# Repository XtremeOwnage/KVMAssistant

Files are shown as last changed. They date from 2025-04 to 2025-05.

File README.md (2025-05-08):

# KVMAssistant

Hardware based solution for home-assistant control over KVMs.

The initial goal of this project is to enable plug and play home assistant control over common off the shelf consumer KVM units.

I have multiple CKL-KVM units to test with, as well as no-name unit, and a TESSMart.

Depending, on how much interest this project gets, depends on how far it goes.

Board was originally built with KiCAD, but, moved to EasyEDA as getting the correct parts was quite a bit easier.

If you wanted to build one, every EXCEPT the ESP will cost.... under 3$.

## Coming soon

Initial schematic design completed. Not perfect, but, good enough to send in an order for PCBs and parts.

Parts were ordered a few weeks ago, pending arrival.

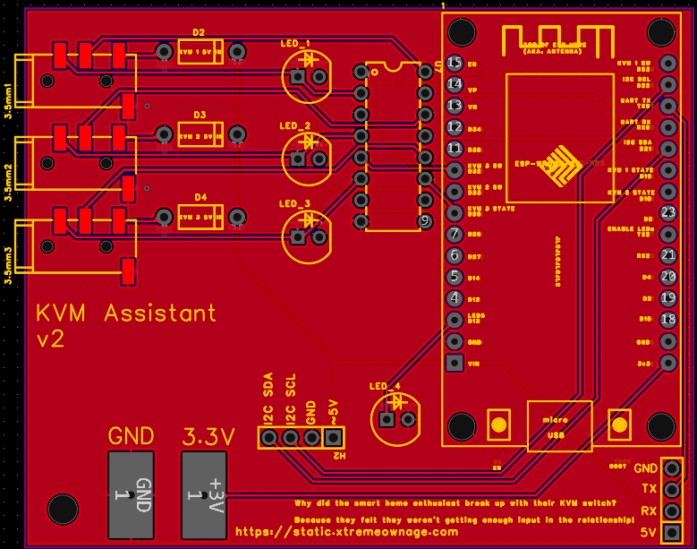
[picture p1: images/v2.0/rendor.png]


Schematic

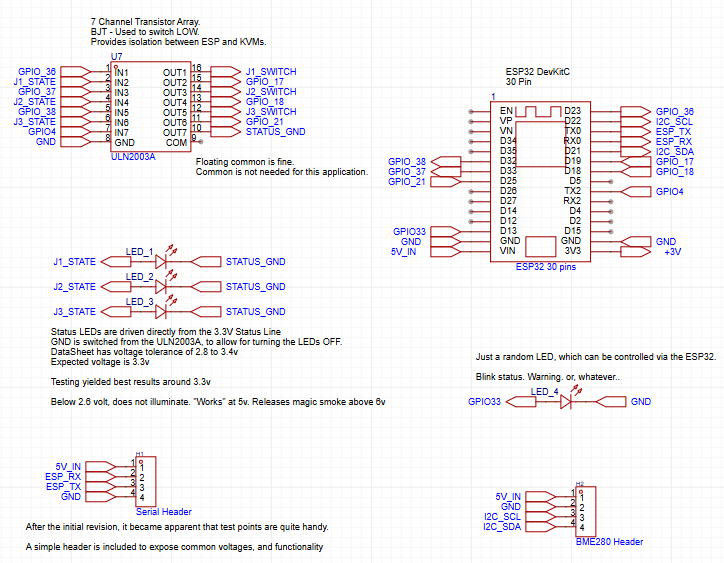
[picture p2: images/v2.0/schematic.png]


Assembled

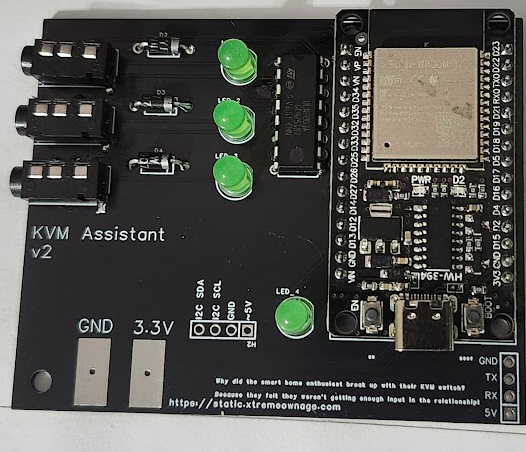
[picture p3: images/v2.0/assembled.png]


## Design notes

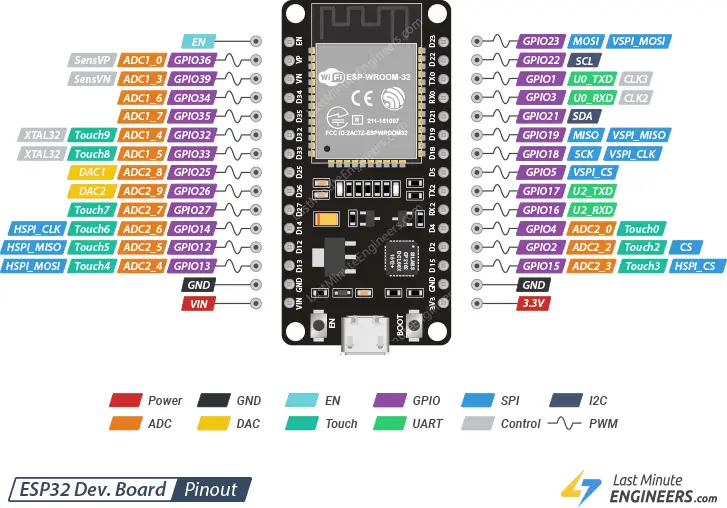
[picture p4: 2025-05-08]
images/v2.0/esp32-pinout.png

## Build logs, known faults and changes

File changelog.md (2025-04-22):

## Change History

### Version 2

1. Removed 4th KVM Input.
2. Removed Optocoupler array, Use 3 unused ports from ULN2003A instead.
3. Removed resistors on LED lines. LEDs are 3.3-5v tolerant. 
4. Removed resistors from optocoupler.
5. Added test pads. Added serial headers.
    - Kind of a PITA to troubleshoot when you cannot hook onto any of the SMT components.
6. Added front/rear ground planes.
7. Updated footprint to leverage COMMONLY available ESP32 Devkit footprints, and not the obscure 48pin one from version 1.
8. Added ability to globally enable/disable all LEDs via ESP.
    - Useful if you want to be able to turn all of the LEDs on or off.
9. Simplified everything.
10. Added mounting holes
11. Added labels everywhere.
    - Much easier to troubleshoot when everything is labeled.
12. Added a REALLY bad pun to the silkscreen.

#### Version 2.1

1. Removed copper fill behind ESP's antenna

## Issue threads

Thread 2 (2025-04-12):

Use standard ESP32 headers, instead of ESP32-DevkitC

XtremeOwnageDotCom, 2025-04-12:
The ESP32-C2DevkitC boards are rather... expensive.

Using the standard ESP32 design would enable much cheaper sourcing of ESP32s & Replacements. It would also free up a bit of space on the PCB itself.

XtremeOwnageDotCom, 2025-04-20:
Resolved by #5

Closed 2025-04-20.

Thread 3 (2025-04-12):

Add Capacitors Pre/Post AMS1117

XtremeOwnageDotCom, 2025-04-12:
Per [Datasheet](http://www.advanced-monolithic.com/pdf/ds1117.pdf), should have an output capacitor in the design.

However, I was in a hurry late Sunday night, and forgot to put in the capacitor before ordering the first shipment of boards. Oops.

Add output capacitor to the 3v rail.

XtremeOwnageDotCom, 2025-04-20:
Indirectly resolved by #5 .

Since the dedicated AMS1117 has been removed, and we are instead using the AMS1117 on the ESP32's devkit.... It has its own capacitors. So, no need to add more!

Closed 2025-04-20.

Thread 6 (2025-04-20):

The space underneath the PCB antenna should be copper free

nepozs, 2025-04-20:
This is actually a design error that limits the range of the WiFi module used.
The principles of designing the RF track area are well presented in the Espressif documentation.
https://docs.espressif.com/projects/esp-hardware-design-guidelines/en/latest/esp32/pcb-layout-design.html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

XtremeOwnageDotCom, 2025-04-20:
Hows this? https://github.com/XtremeOwnage/KVMAssistant/tree/v0.2/EasyEDA

Closed 2025-04-22.

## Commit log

2025-03-10 Added status LEDs.
    [KVM-Control.kicad_pcb, KVM-Control.kicad_sch, inputs.kicad_sch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]
2025-04-12 Removed KiCAD files.
    [KVM-Control.kicad_pcb, KVM-Control.kicad_sch, esp32_logic.kicad_sch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]
2025-04-20 2.1 - Remove copper fill behind antenna.
2025-05-03 Added v2 assembly/photos.
2025-05-03 Added ESP32 Pinout.
